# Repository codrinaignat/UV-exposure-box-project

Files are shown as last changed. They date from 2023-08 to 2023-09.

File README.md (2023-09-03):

# UV-exposure-box-project

Project structure:
- Proteus folder: contains the Proteus simulation of the schematic for the UV exposure box;
- UV_exposure_box_beta and UV_exposure_box folders contain the PCB and schematic of the project in KiCAD; the beta folder is a more recent version of the project;
- uC program folder contains the MPLABX IDE files for the microcontroller, meaning the C code and additional files;
- Necesare.docx is a list of the necessary components in order to build an UV exposure box from scratch. The list is in Romanian;
- UV_exposure_box.pdf is the schematic of the project, in KiCAD.

The project's purpose is to make the PCB creation process easier. The UV exposure is necessary when you want to create a PCB using a photoresist copper board. 
The box has buttons to set the exposure time, to start and stop the exposure.

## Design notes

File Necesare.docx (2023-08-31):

Necesare pentru expunere:
- solutie developare
- foaie de calc
- clorura ferica
- placi fotorezist

Componente cutie UV:
- cutie lemn/plastic
- silicon
- 2 placi cu insule sau una mare pt matrice leduri
- PCB-ul cu traseele
- sursa 230-5V 4A
- fire groase
- display LCD
- 5 butoane
- silicon transparent
- plexiglas
- carton pt partea opusa ledurilor
- switch alimentare
- cablu alimentare
- siguranta fuzibila 3A
- LED-uri UV: UV3TZ-405-30 Bivar, UV LED, 405nm 40mW 30 °, 2-Pin Through Hole package
- rezistente tht 120 ohm
- fire jumper pentru butoane si LCD

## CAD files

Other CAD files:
uC program/dist/default/production/uC_program.production.obj
uC program/l.obj

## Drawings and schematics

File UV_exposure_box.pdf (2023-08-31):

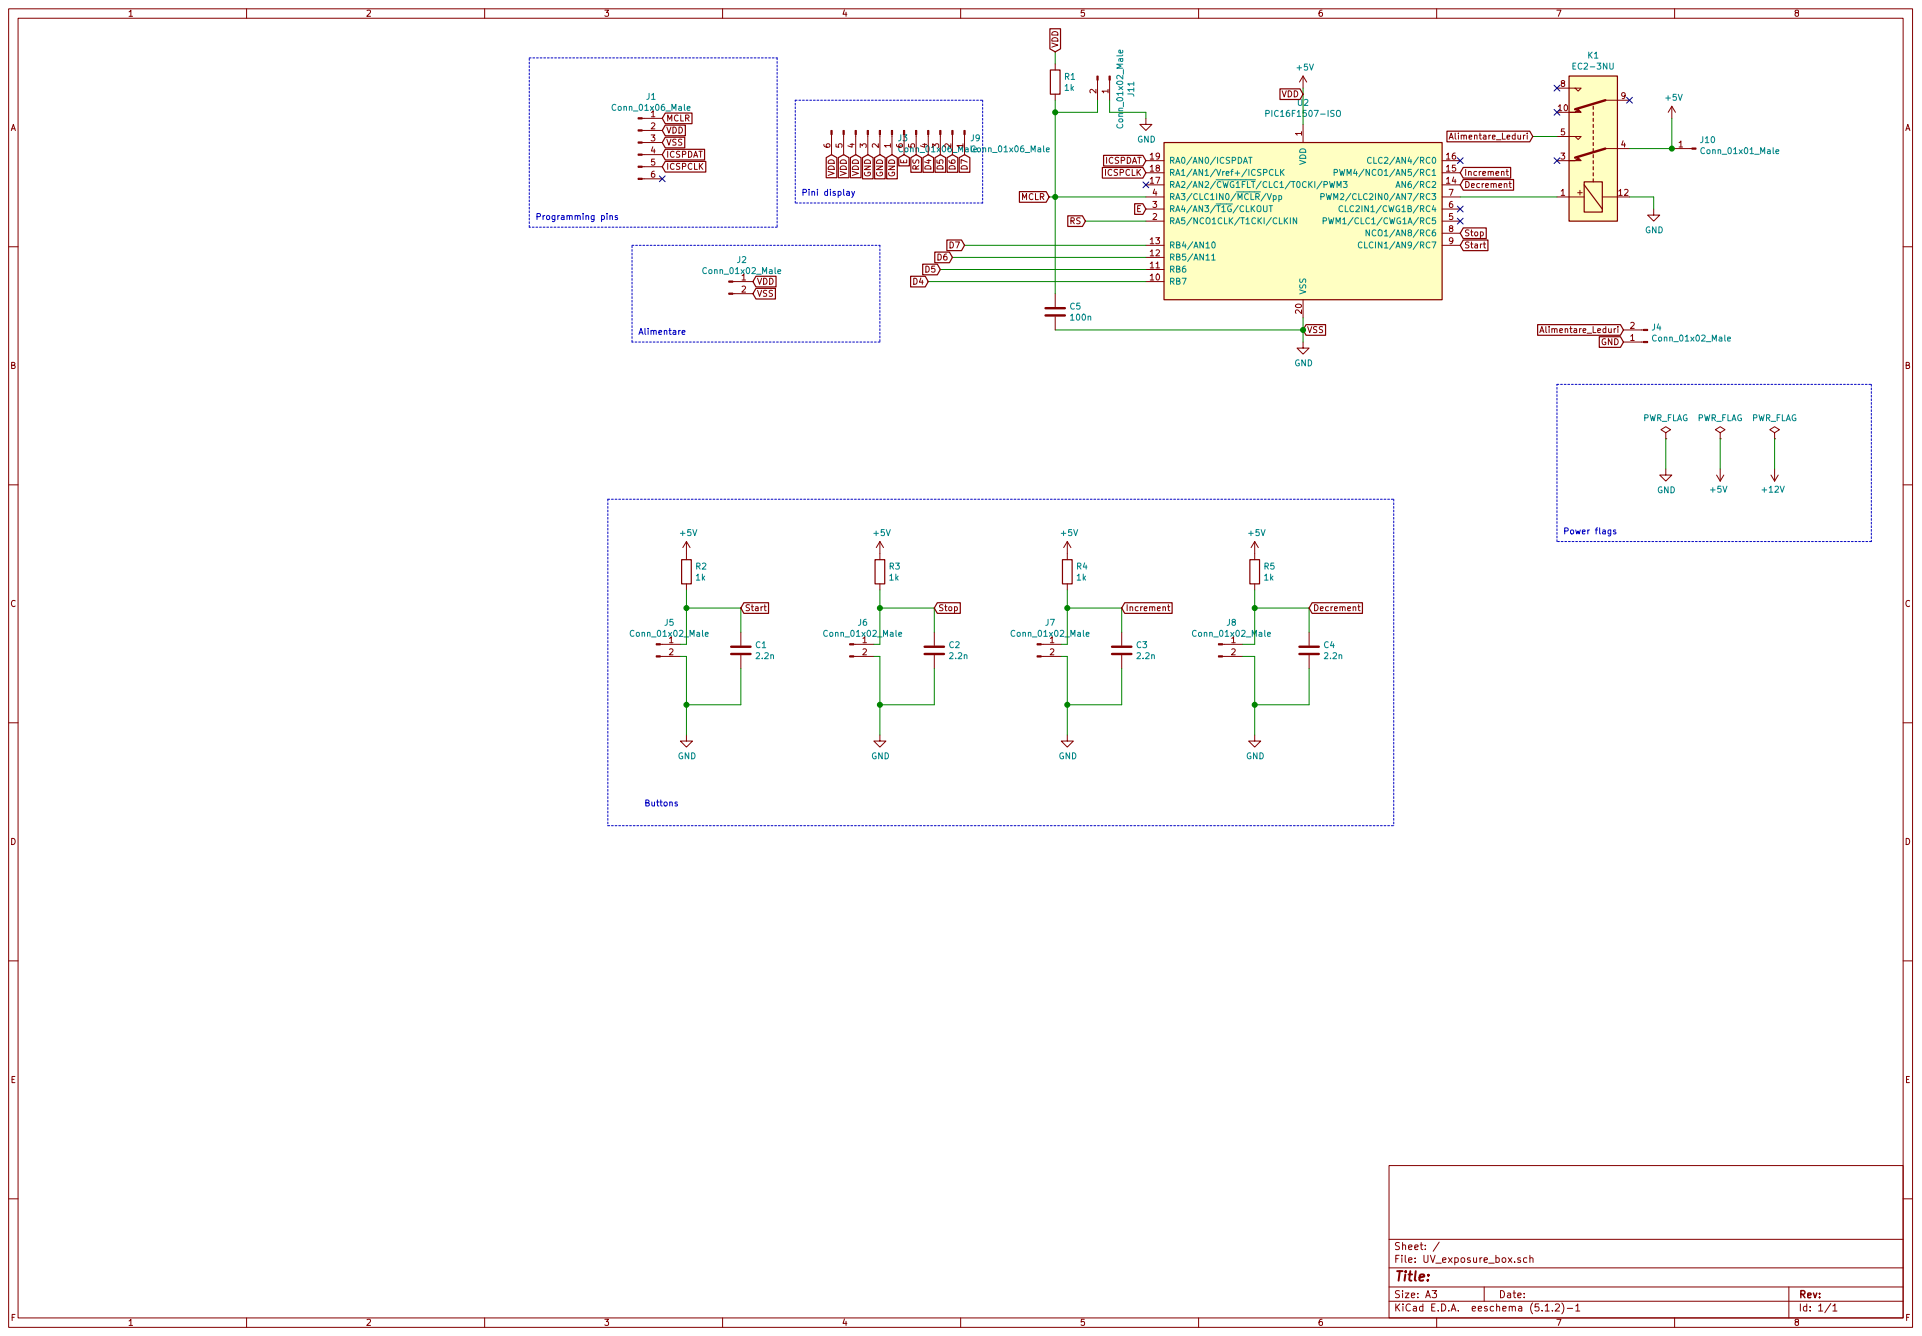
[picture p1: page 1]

1 RB7 10 RB6 11 RB5/AN11 12 RB4/AN10 13 AN6/RC2 14 PWM4/NCO1/AN5/RC1 15 CLC2/AN4/RC0 16 RA2/AN2/CWG1FLT/CLC1/T0CKI/PWM3 17 RA1/AN1/Vref+/ICSPCLK 18 RA0/AN0/ICSPDAT 19 RA5/NCO1CLK/T1CKI/CLKIN 2 VSS 20 RA4/AN3/T1G/CLKOUT 3 RA3/CLC1IN0/MCLR/Vpp 4 PWM1/CLC1/CWG1A/RC5 5 CLC2IN1/CWG1B/RC4 6 PWM2/CLC2IN0/AN7/RC3 7 NCO1/AN8/RC6 8 CLCIN1/AN9/RC7 9 U2 PIC16F1507-ISO

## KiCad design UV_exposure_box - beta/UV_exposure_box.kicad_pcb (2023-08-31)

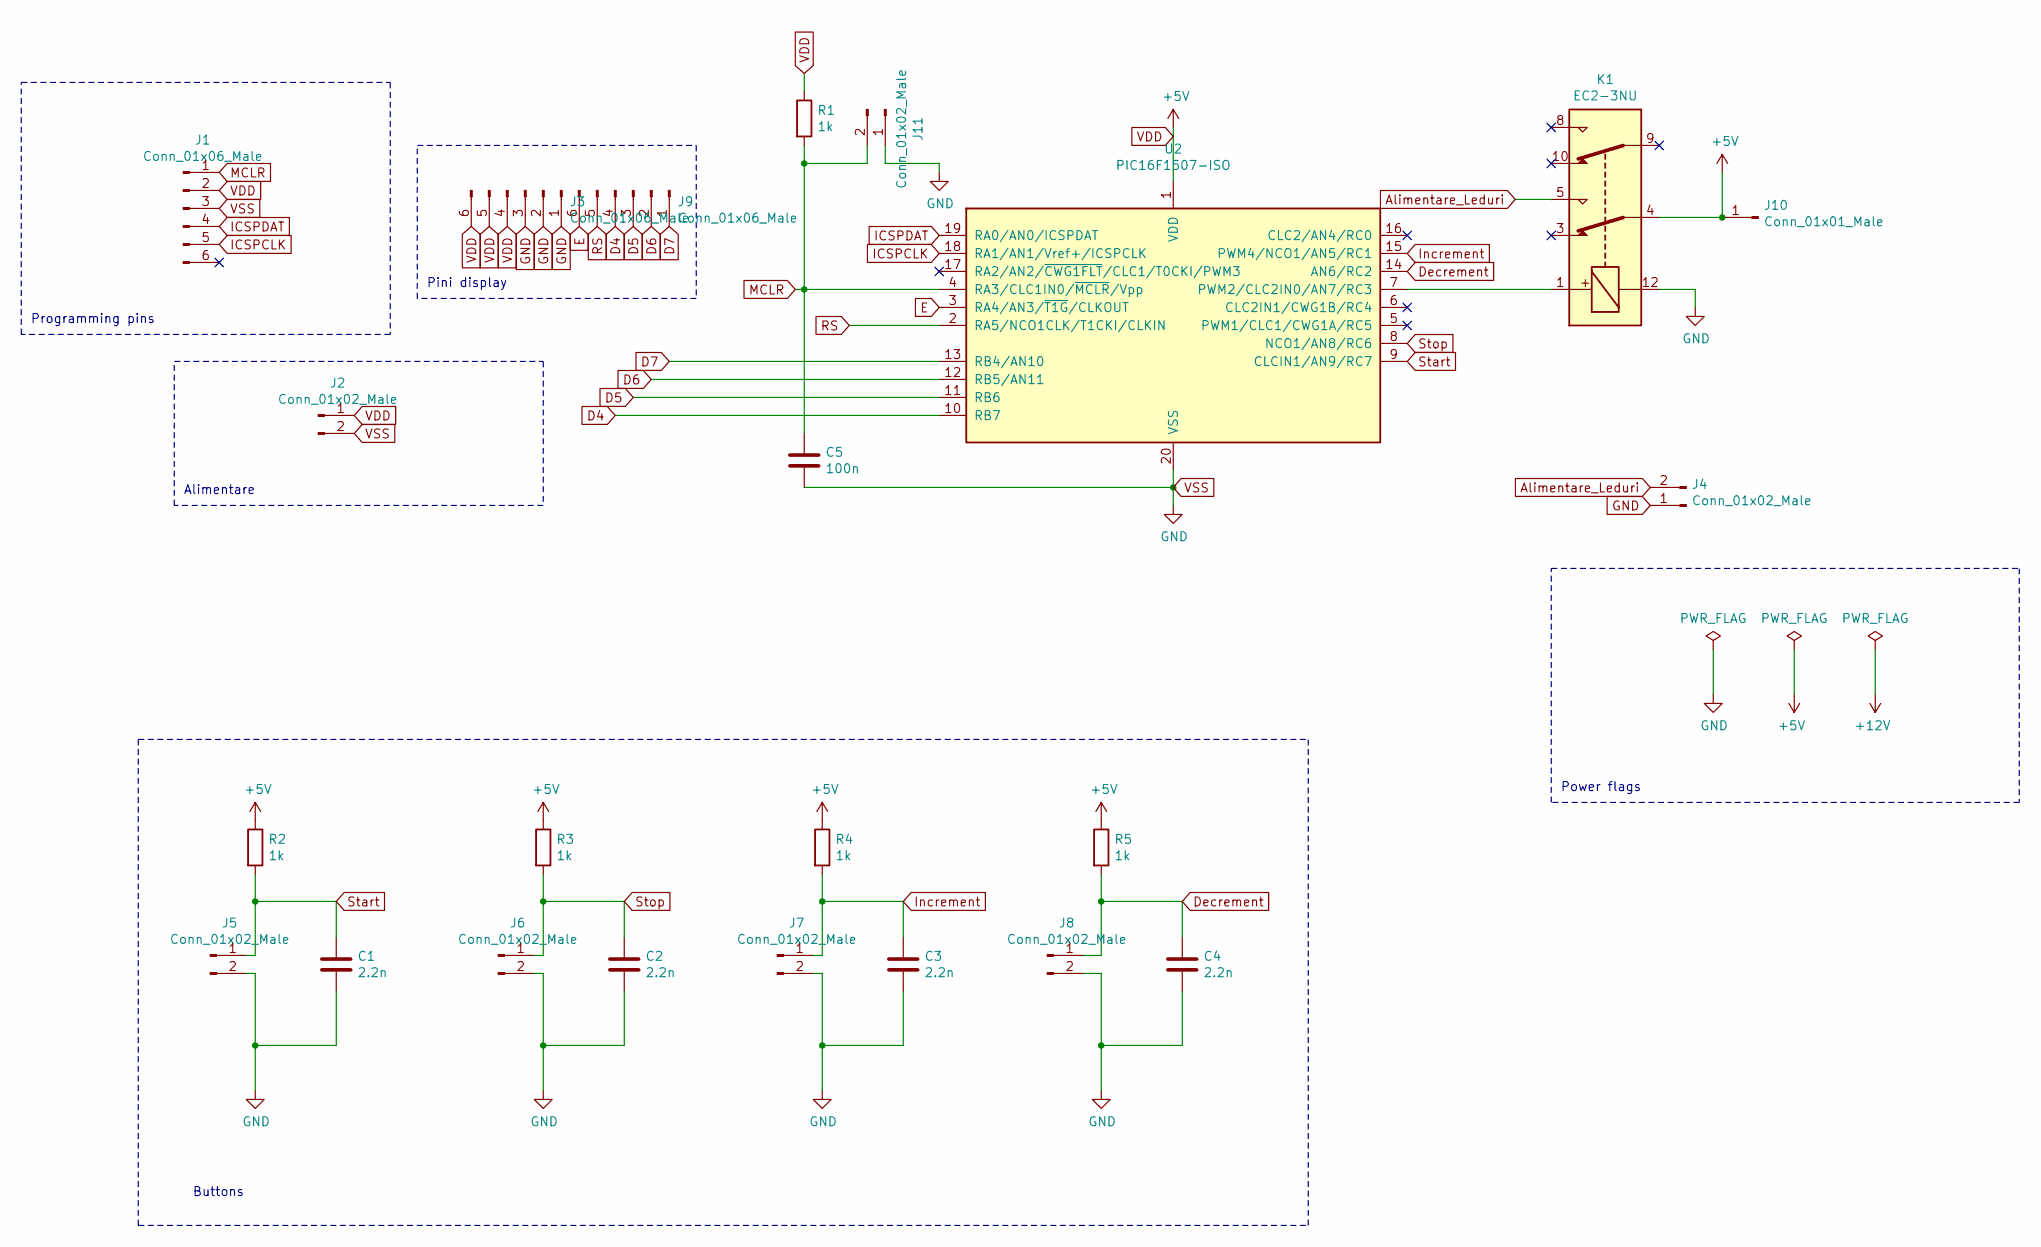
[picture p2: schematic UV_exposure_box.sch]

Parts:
C1, C2, C3, C4: 2.2n; C_1206_3216Metric
C5: 100n; C_1206_3216Metric
J1, J3, J9: Conn_01x06_Male; PinHeader_1x06_P2.54mm_Vertical
J2, J4, J5, J6, J7, J8, J11: Conn_01x02_Male; PinHeader_1x02_P2.54mm_Vertical
J10: Conn_01x01_Male; PinHeader_1x01_P2.54mm_Vertical
K1: EC2-3NU; Relay_DPDT_Omron_G6S-2G
R1, R2, R3, R4, R5: 1k; R_1206_3216Metric
U2: PIC16F1507-ISO; SOIC-20W_7.5x12.8mm_P1.27mm

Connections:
Alimentare_Leduri: J4.2, K1.5
D4: J9.4, U2.10 (RB7)
D5: J9.3, U2.11 (RB6)
D6: J9.2, U2.12 (RB5/AN11)
D7: J9.1, U2.13 (RB4/AN10)
Decrement: C4.1, J8.1, R5.2, U2.14 (AN6/RC2)
E: J9.6, U2.3 (RA4/AN3/~T1G~/CLKOUT)
GND: C1.2, C2.2, C3.2, C4.2, C5.2, J1.3, J2.2, J3.1, J3.2, J3.3, J4.1, J5.2, J6.2, J7.2, J8.2, J11.1, K1.12, U2.20 (VSS)
ICSPCLK: J1.5, U2.18 (RA1/AN1/Vref+/ICSPCLK)
ICSPDAT: J1.4, U2.19 (RA0/AN0/ICSPDAT)
Increment: C3.1, J7.1, R4.2, U2.15 (PWM4/NCO1/AN5/RC1)
MCLR: C5.1, J1.1, J11.2, R1.2, U2.4 (RA3/CLC1IN0/~MCLR~/Vpp)
unnamed: K1.1, U2.7 (PWM2/CLC2IN0/AN7/RC3)
RS: J9.5, U2.2 (RA5/NCO1CLK/T1CKI/CLKIN)
Start: C1.1, J5.1, R2.2, U2.9 (CLCIN1/AN9/RC7)
Stop: C2.1, J6.1, R3.2, U2.8 (NCO1/AN8/RC6)
VDD: J1.2, J2.1, J3.4, J3.5, J3.6, J10.1, K1.4, R1.1, R2.1, R3.1, R4.1, R5.1, U2.1 (VDD)

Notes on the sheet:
Programming pins
Alimentare
Power flags
Pini display
Buttons

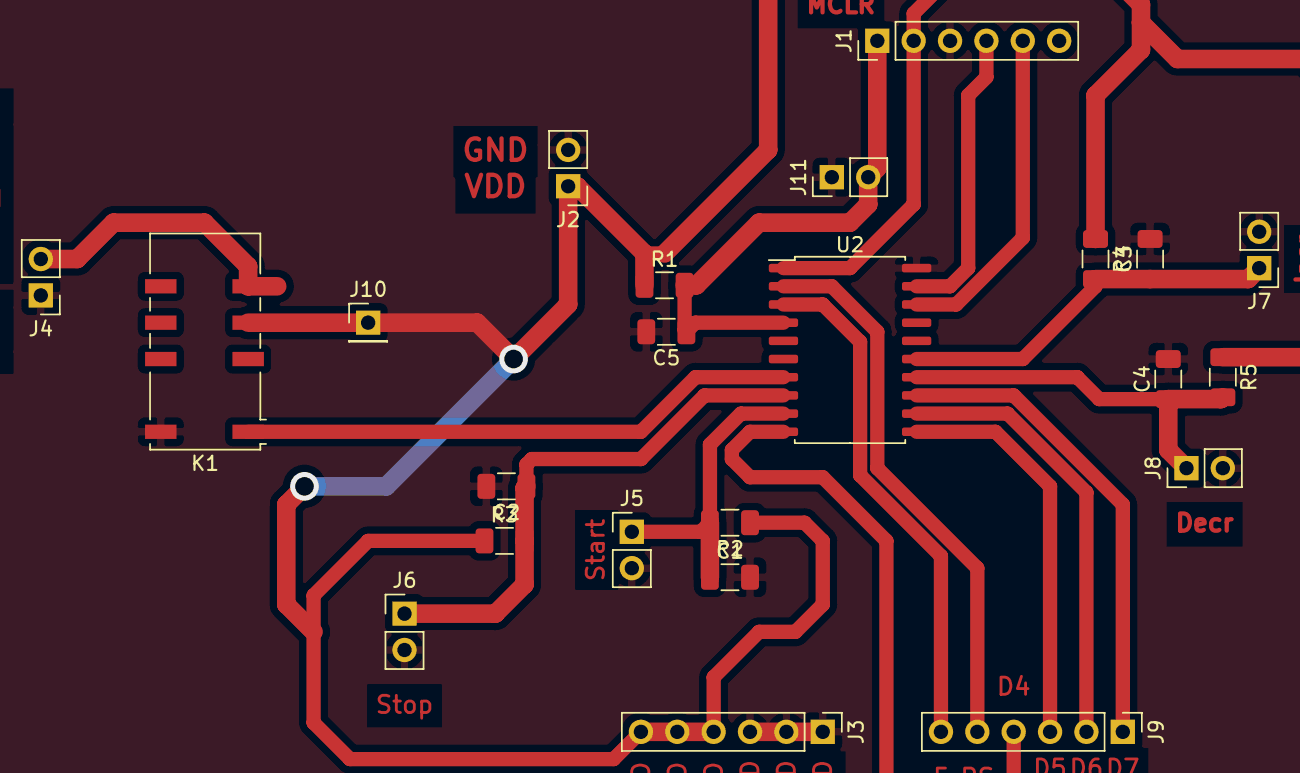
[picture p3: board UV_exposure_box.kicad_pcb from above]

Board: 2 copper layers, 23 parts (0 on the bottom side), 17 nets.

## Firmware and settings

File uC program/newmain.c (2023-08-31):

#include "newxc8_header.h"
#include <xc.h>
#include <stdbool.h>


#define _XTAL_FREQ 10000000
// LCD pins
#define EN PORTAbits.RA4
#define RS PORTAbits.RA5
#define D4 PORTBbits.RB7
#define D5 PORTBbits.RB6
#define D6 PORTBbits.RB5
#define D7 PORTBbits.RB4

#define Relay_Control PORTCbits.RC3

//buttons
#define Increment_Button PORTCbits.RC1
#define Decrement_Button PORTCbits.RC2
#define Start_Button PORTCbits.RC7
#define Stop_Button PORTCbits.RC6

int contor = 0;
char Buffer[3];
int check=false;

void Lcd_SetBit(char data_bit) {
    if (data_bit & 1)
        D4 = 1;
    else
        D4 = 0;

    if (data_bit & 2)
        D5 = 1;
    else
        D5 = 0;

    if (data_bit & 4)
        D6 = 1;
    else
        D6 = 0;

    if (data_bit & 8)
        D7 = 1;
    else
        D7 = 0;
}

void Lcd_Cmd(char a) {
    RS = 0;
    Lcd_SetBit(a); //Incoming Hex value
    EN = 1;
    __delay_ms(5);
    EN = 0;
}

void Lcd_Clear() {
    Lcd_Cmd(0); //Clear the LCD
    Lcd_Cmd(1); //Move the cursor to first position
}

void Lcd_Set_Cursor(char a, char b) {
    char temp;
    char z = 0;
    char y = 0;
    if (a == 1) {
        //(Chapter 1.1)
        temp = 0x80 + b - 1;
        z = temp >> 4; //Lower 8-bits
        y = temp & 0x0F; //Upper 8-bits
        Lcd_Cmd(z); //Set Row
        Lcd_Cmd(y); //Set Column
    } else if (a == 2) {
        //(Chapter 1.2)
        temp = 0xC0 + b - 1;
        z = temp >> 4; //Lower 8-bits
        y = temp & 0x0F; //Upper 8-bits
        Lcd_Cmd(z); //Set Row
        Lcd_Cmd(y); //Set Column
    }
}

void Lcd_Start() {
    //driver controller SPLC780D
    Lcd_SetBit(0x00);
    int i;
    for (i = 32767; i <= 0; i--) NOP();
    Lcd_Cmd(0x03); //1
    __delay_ms(1);
    Lcd_Cmd(0x03); //2
    __delay_ms(1);
    Lcd_Cmd(0x03); //3
    Lcd_Cmd(0x02); //4
    Lcd_Cmd(0x02); //5
    Lcd_Cmd(0x08); //6
    Lcd_Cmd(0x00); //7
    Lcd_Cmd(0x0C); //8
    Lcd_Cmd(0x00); //9
    Lcd_Cmd(0x06); //10

}

void Lcd_Print_Char(char data) //Send 8-bits through 4-bit mode
{
    char Lower_Nibble;
    char Upper_Nibble;
    Lower_Nibble = data & 0x0F; 

    RS = 1; //
    Lcd_SetBit(Upper_Nibble >> 4); // transmit Upper_Nibble dar shiftat cu 4 bit -  0000 1011
    EN = 1;
    int i;
    for (i = 32767; i <= 0; i--) NOP(); 
    EN = 0;
    Lcd_SetBit(Lower_Nibble); 
    EN = 1;
    for (i = 32767; i <= 0; i--) NOP();
    EN = 0;
}

void Lcd_Print_String(char *a) {
    int i;
    for (i = 0; a[i] != '\0'; i++)
        Lcd_Print_Char(a[i]);
}

char* itoa(int i, char b[]) {
    char const digit[10] = "0123456789";
    char* p = b;
    if (i < 0) {
        *p++ = '-';
        i *= -1;
    }
    int shifter = i;
    do { //Move to where representation ends
        ++p;
        shifter = shifter / 10;
    } while (shifter);
    *p = ' '; /
    do {
        *--p = digit[i % 10];
        i = i / 10;
    } while (i);
    return b;
}

void initializing() {
    Lcd_Start();
        Lcd_Clear();
    Lcd_Set_Cursor(1, 1);
    Lcd_Print_String("Booting.");
    __delay_ms(1);
    Lcd_Set_Cursor(2, 1);
    Lcd_Print_String("...");
    __delay_ms(666);
    Lcd_Clear();
    Lcd_Set_Cursor(1, 1);
    Lcd_Print_String("Booting.");
    __delay_ms(1);
    Lcd_Set_Cursor(2, 1);
    Lcd_Print_String("..");
    __delay_ms(666);
    Lcd_Clear();
    Lcd_Set_Cursor(1, 1);
    Lcd_Print_String("Booting.");
    __delay_ms(1);
    Lcd_Set_Cursor(2, 1);
    Lcd_Print_String(".");
    __delay_ms(666);
    Lcd_Clear();
    Lcd_Set_Cursor(1, 1);
    Lcd_Print_String("Booting.");
    __delay_ms(666);
    Lcd_Clear();
    Lcd_Set_Cursor(1, 1);
    Lcd_Print_String("UVBox v.");
    __delay_ms(1);
    Lcd_Set_Cursor(2, 1);
    Lcd_Print_String("088 Beta ");
    __delay_ms(999);
    Lcd_Clear();
    Lcd_Set_Cursor(1, 1);
    Lcd_Print_String("EMC Engi");
    __delay_ms(1);
    Lcd_Set_Cursor(2, 1);
    Lcd_Print_String("neering");
    __delay_ms(999);
    
    
}
void main(void) {
    OSCCON = 0b01110010;
    TRISA = 0;
    TRISB = 0;
    ANSELA = 0;
    ANSELB = 0;
    ANSELC = 0;
    TRISCbits.TRISC1 = 1; //increment
    TRISCbits.TRISC2 = 1; //decrement
    TRISCbits.TRISC7 = 1; //start
    TRISCbits.TRISC6 = 1; //stop
    TRISCbits.TRISC3 = 0; //relay_control
    Relay_Control
    initializing();
    contor=101;
    int i;
    Lcd_Clear();
    itoa(contor, Buffer);
    Lcd_Set_Cursor(1, 1);
        for (i = 0; i < 3; i++) 
        {
            Lcd_Print_Char(Buffer[i]);
        }
    Lcd_Set_Cursor(1, 5);
    Lcd_Print_String("seco");
    Lcd_Set_Cursor(2, 1);
    Lcd_Print_String("nds");
    int j;
    while (contor < 300) {
            if (Increment_Button == 0) {
                Lcd_Clear();
                if (contor == 299)
                {

                    Lcd_Clear();
                    Lcd_Set_Cursor(1, 1);
                    Lcd_Print_String("Maximum!");
                }
                else
                {
                Lcd_Clear();
                contor = contor + 1;
                itoa(contor, Buffer);
                
                Lcd_Clear();
                Lcd_Set_Cursor(1, 1);
                for (j = 0; j < 3; j++) {
                    Lcd_Print_Char(Buffer[j]);
                }
                Lcd_Set_Cursor(1, 5);
                Lcd_Print_String("seco");
                Lcd_Set_Cursor(2, 1);
                Lcd_Print_String("nds");
                __delay_ms(30);

            }
            }
            if (Decrement_Button == 0) {
                Lcd_Clear();
                if (contor < 100)
                {

                    Lcd_Clear();
                    Lcd_Set_Cursor(1, 1);
                    Lcd_Print_String("Min. 100");
                    Lcd_Set_Cursor(2, 1);
                    Lcd_Print_String(" seconds");
                }
                else
                {
                contor = contor - 1;
                itoa(contor, Buffer);

                Lcd_Clear();
                Lcd_Set_Cursor(1, 1);
                for (j = 0; j < 3; j++) {
                    Lcd_Print_Char(Buffer[j]);
                }
                Lcd_Set_Cursor(1, 5);
                Lcd_Print_String("seco");
                Lcd_Set_Cursor(2, 1);
                Lcd_Print_String("nds");
                __delay_ms(30);
            }
            }
            if (Start_Button == 0) {
                Lcd_Clear();
                __delay_ms(500);
                Lcd_Clear();
                if (contor >=0 && contor <=99 )
                {

                    Lcd_Clear();
                    Lcd_Set_Cursor(1, 1);
                    Lcd_Print_String("Min. 100");
                    Lcd_Set_Cursor(2, 1);
                    Lcd_Print_String(" seconds");
                }
                else{
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
